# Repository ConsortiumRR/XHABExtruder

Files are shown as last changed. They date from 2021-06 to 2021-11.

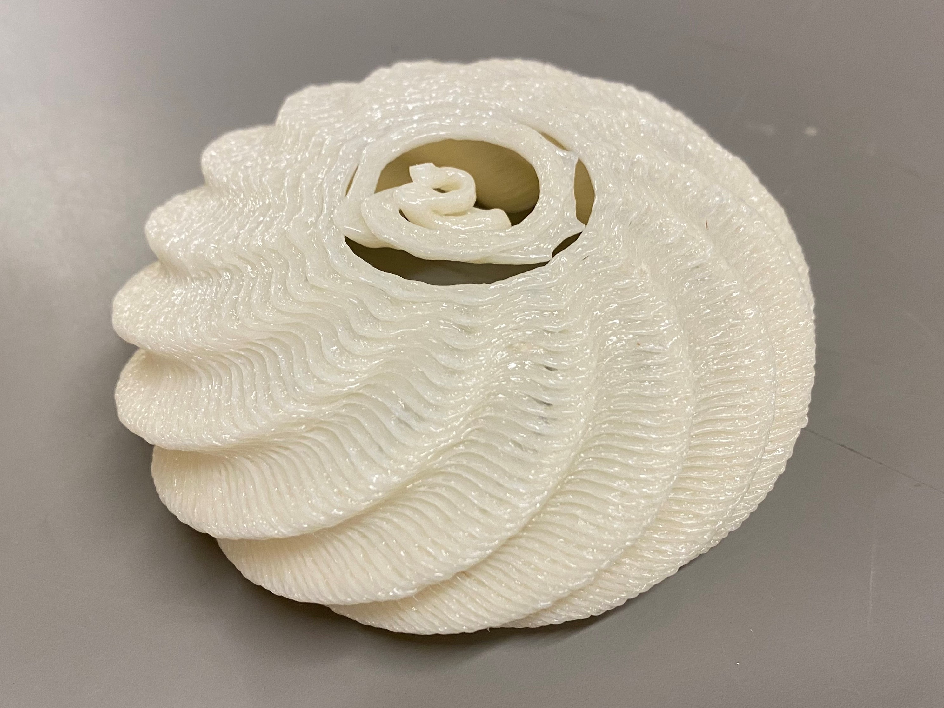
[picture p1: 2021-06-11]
Other Documentation/PrintTest_Spiral_0322.jpg

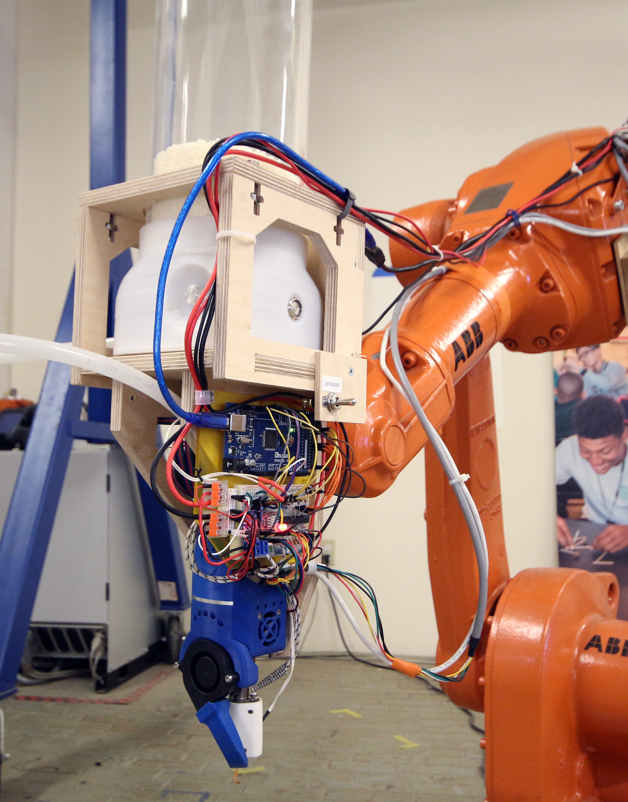
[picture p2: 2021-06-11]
Tool/3quarter_tool.jpg

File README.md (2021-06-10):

# XHABExtruder
 
An experimental 3D printing extruder tool for an industrial robotic arm developed for the NASA XHAB design studio at Pratt Institute.

This project utilizes the Lily Pellet extruder kit and with a custom controller developed on the Arduino Mega/ ESP32 microcontroller. The robot is programmed in grasshopper to follow printing toolpaths and communicates via IO pulses to sync extruder operation.

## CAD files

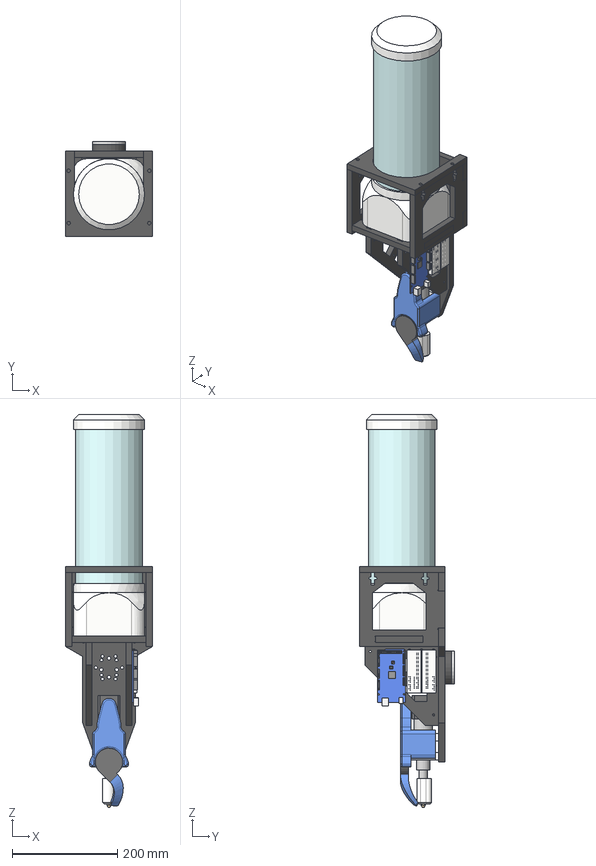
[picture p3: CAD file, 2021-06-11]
Tool/XHABExtruder_ProtoBracketV2.step
165.0 x 180.0 x 745.2 mm
Robotic Faceplate
PelletHopper
HalfBreadboard_light
Arduino Mega

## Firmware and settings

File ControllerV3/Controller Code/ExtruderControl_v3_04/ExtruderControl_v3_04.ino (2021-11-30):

// V3_04 - using ATtiny85 over I2C
// formated some things to be constant between motormode and pulses
//tested 
//revert to V3_03 to return to no atTiny

//---------------------------------------Libraries-----------------------------------------//
#include <PID_v1.h>
#include <Wire.h> //for I2C/ SPI

//#include <HardwareSerial.h> //for UART
//#include <PubSubClient.h> //nodered
//#include <Wifi.h>
//#include <ArduinoJson.h> //nodered
//#include <AccelStepper.h>

// LCD display library

//---------------------------------------TEMP-VARIABLES-----------------------------------------//
//Temp Reading Info
#define THERMISTORPIN 36
#define THERMISTORNOMINAL 100000  
#define TEMPERATURENOMINAL 25
#define TEMPVCC 3.3
#define ADCSAMP 4095   
#define SERIESRESISTOR 330
#define NUMSAMPLES 5
#define BCoeff 4007.5
#define c1 0.7493611e-03
#define c2 2.0899615e-04
#define c3 1.3007668e-07
#define TEMP_VOUT 32 //IO as power pin for thermistor

//PWM pin for heater control
#define MOS_PIN 4
#define MOS_CHAN 0

//PID parameters
//uint16_t temp_set = 290; // target temp for extruder - move to bottom section
double Input=25, Output, Setpt;
//double aggKp=20, aggKi=2, aggKd=.2;
double consKp=20, consKi=.5, consKd=5;

PID myPID(&Input, &Output, &Setpt, consKp, consKi, consKd, DIRECT);

bool HeatOn = true;
bool extruderready = false;
//-------------------------------------------------------------------------------//

//---------------------------------------ROBOT-COMS-VARIABLES-----------------------------------------//
bool ModeIn_pulse = true; 
bool ModeOut_GO = true;

// vars for binary signal mode (can be removed for one way pulse operation)
#define numiBits 4
#define numoBits 4
//input (ABB-> Hub) IO binary pins
const uint8_t ibit0 = 16, ibit1 = 17, ibit2 = 18, ibit3 = 19;
uint8_t diPin[] = {ibit0, ibit1, ibit2, ibit3};
//output (Hub->ABB) IO binary pins
const uint8_t obit0 = 25, obit1 = 26, obit2 = 27, obit3 = 33;
uint8_t doPin[] = {obit0, obit1, obit2, obit3};

//Pulse Read Vars
const byte READ_PIN = ibit0; // Pin to read pulses from (needs to be an interrupt pin)
volatile unsigned long pulselen;
const uint8_t numPulse = 7;
const uint16_t pulselengths[numPulse] = {5000, 10000, 15000, 25000, 35000, 40000, 45000}; //set pulse lengths in microseconds
const char  *pulsecommand[] = {"NONE","STOP","FORWARD", "RETRACT", "LOWER SPEED", "RAISE SPEED", "CHECK HEAT", "SYSTEM OFF"}; 
uint16_t pulsetolerance = 700;

bool trigger = false;
//-------------------------------------------------------------------------------//

//---------------------------------------MOTOR-VARIABLES-----------------------------------------//
bool motorSwitchState = LOW; 
// this has been delegated to attiny85
uint8_t motormode = 0;
const byte motorSub = 0x9; 
//structure messages like "[Command Char]:["3CharPositiveValue"]" 
//eg "F:200" = forward 200 step/s, "S","STOP","S:000" stops stepper, "R:100" retract at 100 step/s
//"D", "E" disables and enables stepper driver (this shouldn't be done often)
//"I[char]:[positiveValue]" changes stepper varaibles, "IA" for acceleration, "ID" for default speed, "IM" for max speed 
//Request events with 5 bytes return motor state / feed rate, request with 12 bytes for current settings "accel, max speed, default speed"
//-------------------------------------------------------------------------------//

//---------------------------------------INTERFACE-VARIABLES-----------------------------------------//
// will put in some variables for lcd, buttons/knobs to allow direct user input on tool
//-------------------------------------------------------------------------------//

bool debugging = false; // a lil bool to print to serial when debugging
uint8_t OVERRIDE_PIN = 34; // toggle switch to use robot or override
uint8_t DRIVE_PIN=35; // direction for override
uint8_t READYLED_PIN = 23; // LED to show temp status

// -------> EDIT PRIMARY VARIABLES HERE<------------------------------------------------------------------------//
uint16_t STEP_RATE = 200; //val for forward extrusion rate steps per second 
uint16_t temp_set = 190; // target temp for extruder 
uint16_t displayinterval = 3000; // number of milliseconds to wait between display loop to prevent delays due to serial write
uint8_t inputquery = 0; 

//>>>>>SETUP<<<<<-----------------------------------------------------------------------//
void IRAM_ATTR PulseTrigger(){
  static uint8_t lastState;
  static unsigned long startTime = 0;
  uint8_t readState = digitalRead(READ_PIN);
  if (readState != lastState){
    if (readState==LOW) startTime=micros();
    else{
      pulselen = micros()-startTime; 
      trigger = true; 
    }
    lastState = readState; 
  }
}

//>>>>>SETUP<<<<<-----------------------------------------------------------------------//
void setup() {
  Serial.begin(115200);
  Wire.begin();
  
  pinMode(OVERRIDE_PIN, INPUT);
  pinMode(DRIVE_PIN, INPUT);
  pinMode(READYLED_PIN, OUTPUT);
  pinMode(TEMP_VOUT, OUTPUT);
  
  //Set up outputs for mosfet
  ledcSetup(MOS_CHAN, 490, 8);
  ledcAttachPin(MOS_PIN, MOS_CHAN);
  //set up reference and PID mode for temp control
  HeatOn = true; //heat starts on when board is on - robot can disable
  Setpt = temp_set;
  myPID.SetMode(AUTOMATIC);
  digitalWrite(TEMP_VOUT, HIGH);
  
  motormode = 0;
  messageMotor(motormode); //make sure to tell the motor it's off
  
  //Set inputs and outputs for robot comms
  if (ModeIn_pulse == true){
    pinMode(READ_PIN,INPUT_PULLUP);
    attachInterrupt(digitalPinToInterrupt(READ_PIN),PulseTrigger, CHANGE);
    }
  else{
    for (int indexPin = 0; indexPin < numiBits; indexPin++) {
      pinMode (diPin[indexPin], INPUT_PULLUP);
    //attachInterrupt(digitalPinToInterrupt(diPin[indexPin]),InputTrigger, CHANGE);// this might be bad news may need to only interrrupt 1 pin
    }
  }
  if (ModeOut_GO == true){  //Output 
    for (int indexPin = 0; indexPin < numiBits; indexPin++) {
      pinMode(doPin[indexPin], OUTPUT);
    }
  }
}

//>>>>>LOOP<<<<<-----------------------------------------------------------------------//
void loop(){
  static unsigned long loopTimer;
  static unsigned long displaytimer;
  uint8_t  loopWait = 4; // milliseconds between check loop
  
  // trigger state if robotic command detected 
  if (trigger==true)ReadPulse();

  // checks override motor switch states
  if (digitalRead(OVERRIDE_PIN)==LOW){
    if (millis()-loopTimer > loopWait){
      if (digitalRead(DRIVE_PIN)!=motorSwitchState){
        motorSwitchState = digitalRead(DRIVE_PIN);
        if (motorSwitchState ==HIGH)motormode=1;
        else motormode=0;
        messageMotor(motormode);   
        }
        loopTimer = millis();
    }   
  }
  
  //display loop - for LED inidicators, LCD display, serial print and Temp control loop
  if (millis() - displaytimer > displayinterval){
    TempControl();
    if (debugging){
      Serial.print("Motormode:");
      Serial.println(pulsecommand[motormode+1]);
      Serial.print(Setpt);
      Serial.print("\t");
      Serial.print(Input);
      Serial.print("\t");
      Serial.println(Output);
    }
    if (Input < (Setpt-25)){
      extruderready = false;
      if (!debugging)motormode = 0; //prevent cold motor start when debugging is disabled
      digitalWrite(READYLED_PIN,LOW);
    }
    else{
      extruderready = true;
      digitalWrite(READYLED_PIN, HIGH);
    }
    displaytimer = millis();
  }
}

void TempControl(){
  if (HeatOn){
    Input = (readThermistor()+Input)*.5; //average of current and last temp read to smooth out (should be reworked lol)
    double gap = abs(Setpt-Input); //distance away from setpoint
    myPID.SetTunings(consKp, consKi, consKd);
    myPID.Compute();
    if ((Setpt-Input)>10){
      Output = 255;
    }
    else if ((Input-Setpt)>10){
       Output = 0;
    }
    else{
    }
    ledcWrite(MOS_CHAN, Output);
  }
  else{
    ledcWrite(MOS_CHAN,0);
  }
}

void messageMotor(uint8_t in){
 // sends a message to the i2c motor controller sub - this could be expanded with multiple subs
  char motorMessage[6]; 
  // construct message for motorsub
    switch(in){
      case 0: // Stopped (just ensures motor is stopped if this is called)
        sprintf(motorMessage, "S:000");
        break;
      case 1: //Forward
        sprintf(motorMessage,"F:%u", STEP_RATE);
        break;
      case 2: //Retract
        sprintf(motorMessage,"R:%u", STEP_RATE);
        break;    
      case 3: // Enable
        sprintf(motorMessage, "ENABLE");  
        break;  
      case 4: //Disable
        sprintf(motorMessage, "DISBLE"); 
        break;
      }
      //send to sub
      Wire.beginTransmission(motorSub);
      Wire.write(motorMessage);
      Wire.endTransmission();

      //print message to serial to check
      if (debugging){
        Serial.print("sent to motor sub: ");
        for (uint8_t i=0; i<sizeof(motorMessage);i++){
          Serial.print(motorMessage[i]);
        }
        Serial.println();
      }
      //wipe message
      memset(motorMessage, 0, sizeof(motorMessage)); 
  
}
void ReadPulse(){
  for (int i = 0; i < numPulse; i++) {
      if ( abs(pulselen - pulselengths[i]) < pulsetolerance ) {
          inputquery = i+1;
          break; // no need to continue loop if it's already found a motorMode
        }
        else{
        inputquery = 0;
      }
    }
    if (debugging){
      Serial.print("pulse");
      Serial.print(pulselen);
    }
    pulselen = 0; 
    trigger = false;
    
    // if pulse length corresponds with command then execute command
  if (inputquery > 0 && inputquery <= numPulse)ExecuteCommand(inputquery);
  
}

void ExecuteCommand(uint8_t command){
  if (debugging){
    Serial.print("\tcommand = ");
    Serial.println(inputquery);
    Serial.print("Executing Command: ");
    Serial.println(pulsecommand[command]);
  }
  //Execute commands from robot: (excluding none) {"NONE","STOP","FORWARD", "RETRACT", "LOWER SPEED", "RAISE SPEED", "CHECK HEAT", "SYSTEM OFF"}
  switch(command){
    case 1: //Stop extruder
      motormode = 0;  
      messageMotor(motormode);
      break;  
    case 2: //Forward    
      motormode = 1;
      messageMotor(motormode);
      break;    
    case 3: //Retract
      motormode = 2;
      messageMotor(motormode);
      break;
    case 4: // decrease step speed by 50 step/s
      STEP_RATE -= 50; 
      messageMotor(motormode); 
      break;
    case 5: //increase step speed by 50 step/s
      STEP_RATE += 50; 
      messageMotor(motormode); 
      break; 
    case 6: //ensure heat + stepper is on, check if heat is ready
      Serial.println(extruderready);
      HeatOn = true;
      messageMotor(3);
      // if binary output setup send signal to robot
      if (ModeOut_GO){
        if (extruderready)ReturnBinary(1); 
        else ReturnBinary(2);       
      }
      break; 
    case 7: //shuts extruder down  
      motormode = 0;
      messageMotor(4); 
      HeatOn = false;
      break;
  }
}

void ReturnBinary(byte sendval){
  //send a binary signal to the robot to be read from GI
  for (int i = 0; i < numoBits; i++) {
    if (bitRead(sendval, i) == 1) digitalWrite(doPin[i], HIGH);
    else digitalWrite(doPin[i], LOW);
  }
}

double readThermistor(void){
  // maybe rework to read from table instead of all this business
  uint8_t i;
  double average;
  double logR;
  float T;

  average =0;
  for (i=0; i< NUMSAMPLES; i++) {
   average += analogRead(THERMISTORPIN);
  }
  average /= NUMSAMPLES;
  average = (average*TEMPVCC)/ADCSAMP;//convert to volts
  average = SERIESRESISTOR*average/(TEMPVCC-average);
  
  logR = log(average);
  T = (1.0 / (c1 + c2*logR + c3*logR*logR*logR));
  if (T>1)  T -= 273.15; //for low series resistor + ESP32 ADC nonlinearity everything under about 50C reads as O
  return T;
}

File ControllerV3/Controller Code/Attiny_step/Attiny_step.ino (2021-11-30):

// I2C Sub Stepper Control
//PHOEBE DEGROOT - Updated 11/25/21 
// todo:  add more functions (pin allocation, parameters etc) and reduce memory load might need to replace accelstepper due to bloat 

// This ATtiny85 acts as a simple stepper controller using the a stepper driver (eg A4988) and the AccelStepper library
// executes stepper commands-  "STOP" stop stepper, "F:[speed]" run stepper forward at speed
// "R:[speed]" stepper retract at speed, "E" enable stepper, "D" disable stepper

// general format is COMMAND:VALUE - command can be char or string, value is unsigned 16bit  integer
// Syntax rules: need to be under 16 char long, must start with correct command char (can be upper or lower)
// command not case sensitive- use just one char or multiple, ':' can be interchanged with or ','  just dont use twice!
// eg "F:200" , "for:200", "f,0200" all run stepper forward at 200 steps per second
// with no feed set "Forward" and "Retract" will use last feed used or 100step/s if none set
// retract only runs for specified number of steps to protect auger
//'I' intializes different variables with in for value A=accel, R=retract steps(positive!), M= maxspeed
 

#define I2C_SUB_ADDRESS 0x9
//This sub's address is 0x9 or int 9 
#include<TinyWireS.h>
#include<AccelStepper.h>

// ------ ------ ------ STEPPER VARS ------ ------ ------ //
#define LED_PIN 1
uint8_t DIR_PIN =4;
uint8_t STEP_PIN =3;
const uint8_t motorLoop = 1; //loop time for motor running
AccelStepper Extruder(1, STEP_PIN, DIR_PIN);
uint16_t StepSpeed; 
bool motorOn = true;
uint8_t motormode = 0; 
int16_t retractStep = -250;
uint16_t stepAccel = 400;
uint16_t stepMaxSpeed = 500;
uint8_t defaultSpeed = 100;   


// ------ ------ ------ COM VARS ------ ------ ------ //  
#define numChars 16 
char tempChars[numChars]; 
char msgChars[numChars]; 
char msgString[numChars] = {0};
uint16_t msgInt = 0;

bool newMsg = false;
#define cmdNdx 0 //location of first command in message - for quick reactions

// >>>>>> ------ ------ ------ I2C EVENTS ------ ------ ------ <<<<<< //
void receiveEvent(uint8_t num_bytes){
  // returns if number of bytes is too high or low 
  if (num_bytes<1){
    return;
  }
  else if (num_bytes> numChars){
    return;
  }
  
  // data reading - loads msgChars array with each byte
  for (uint8_t i = 0; i<num_bytes; i++){
    msgChars[i] = TinyWireS.receive();
  }
  newMsg = true; 
  // skips parsing if the first char is "S" for stop
  if (msgChars[cmdNdx]=='S' or msgChars[cmdNdx]=='s'){
    motormode = 0; // quick reaction for stoping 
    newMsg = false; 
    return;  
  }
}

// >>>>>> ------ ------ ------ SETUP ------ ------ ------ <<<<<< //
void setup() {
  TinyWireS.begin(I2C_SUB_ADDRESS);
  TinyWireS.onReceive(receiveEvent); 

  pinMode(DIR_PIN,OUTPUT);
  pinMode(STEP_PIN,OUTPUT);
  pinMode(LED_PIN, OUTPUT); 
  Extruder.setAcceleration(stepAccel); 
  Extruder.setMaxSpeed(stepMaxSpeed);
  Extruder.setSpeed(defaultSpeed); 

}

void loop() {
  static unsigned long motorTimer;
  
  TinyWireS_stop_check(); //need to double check use of this function - keep loop tight! tws_delay() instead of delay
    
  if (newMsg){
    //parse message if new
    strcpy(tempChars, msgChars);
    parseMessage(); 
    newMsg = false; 
  }
  // skip timer and motor run if motorOn is false - this should help motor start faster when motorOn is switched to true
  if(motorOn){
    if (millis()-motorTimer>motorLoop){
      runMotor(motormode);
      motorTimer = millis(); 
    }
  } 
}

void parseMessage(){
  // vars to store message command string and int 
  // this could be modified to parse more complex messages - for this stepper the format is String:Int eg F:250 or Forward:250
  char *msgNdx; // pointer index for parsing input message into tokens
  
  msgNdx = strtok(tempChars, ":,"); //split on : , - or space char
  strcpy(msgString, msgNdx); //store first part of message as char array 
  msgString[0] &= 0xDF; //ensure first char is uppercase
  msgString[1] &= 0xDF; //ensure second char is uppercase

  msgNdx = strtok(NULL, ":,"); //continue tokenizing message
  msgInt = atoi(msgNdx); //store next part of message as int 
  getCommand(); 
}

void getCommand(){
  // interprets message using the first char of command string:  STOP, FORWARD, RETRACT, ENABLE, DISABLE
  // could add distance or ability to initialize some variables eg "IA" =>intialize acceleration value
  switch(msgString[0]){
    case 'S':
      motormode = 0; 
      StepSpeed = 0; 
      motorOn = false; 
      break;
    case 'F':
      motormode = 1;
      if (msgInt>0){
        StepSpeed = msgInt;
        defaultSpeed = StepSpeed; 
      }
      else{
        StepSpeed = defaultSpeed;  
      }
      motorOn = true; 
      Extruder.setSpeed(StepSpeed);
      digitalWrite(LED_PIN, HIGH);     
      break; 
    case 'R':
      motormode = 2;
      if (msgInt>0){
        StepSpeed = msgInt;
        defaultSpeed = StepSpeed; 
      }
      else{
        StepSpeed = defaultSpeed;  
      }
      motorOn = true; 
      Extruder.setCurrentPosition(0); 
      Extruder.moveTo(retractStep);
      Extruder.setSpeed(StepSpeed);
      digitalWrite(LED_PIN, HIGH);      
      break; 
    case 'D':
      //disable stepper 
      motormode = 0; 
      motorOn = false; 
      Extruder.disableOutputs();
      break;
    case 'E':
      //enable stepper
      motorOn = true; 
      Extruder.enableOutputs(); 
      break;
    case 'I': //initialize different variables
      switch(msgString[1]){
        case 'A':
        if (msgInt>0)Extruder.setAcceleration(msgInt); 
        break;
        case 'R':
        if (msgInt>0)retractStep=-msgInt; 
        break;
        case 'M':
        if (msgInt>0)Extruder.setMaxSpeed(msgInt); 
        break;
      }
  }
  runMotor(motormode);
}

void runMotor(uint8_t in){ 
  switch(in){
    case 0: //stop
      Extruder.stop();
      digitalWrite(LED_PIN, LOW);
      motorOn = false; 
      break;
    case 1://forward
      Extruder.runSpeed();  
      break;
    case 2://retract
      Extruder.run();
      if (Extruder.distanceToGo()==0){
        Extruder.stop();
        motormode = 0;
      }
      break;
  } 
}

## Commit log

2021-06-10 Controller Code and Circuit Diagram
2021-06-11 XHAB Proto
    added additional documentation
    [XHABExtruder_ProtoBracketV2.step]
